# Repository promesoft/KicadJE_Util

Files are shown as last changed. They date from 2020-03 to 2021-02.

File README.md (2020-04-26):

# KicadJE_Util
CV utility module

# Purpose

## CV Util 1
Input +/- 10V DC

Output +/- 10V DC

Adjustment:

Inv/Noninv (input)

Offset

Gain 

## CV Util 2 - Glide
0-10V input

0-10V Output

## Gate Util 1 - Timing
0-10V input

Time shift of the start and end phase

# Status - TimeShift mounted
## Initial 
| Stage  | Detail | Status |
| --- | --- | --- |
| create material  | sch | ok |
| | pcb | ok |
| | gerber | ok |
| production  | | ok |
|  | produced | ok |
|  | delivered | ok |
## Preliminary validation
| Test  | Detail | Status |
| --- | --- | --- |
| Initial Inspection | | ok |
| Initial Technical Test | Util | ok - but offset pots are reversed |
| Initial Technical Test | Glide | notok - CV in potential burn of output by gnd of tip |
| Initial Technical Test | TimeShift | Ok - but problem in pos/neg detection |
| Initial Product Test | Util |  |
| Initial Product Test | Glide |  |
| Initial Product Test | TimeShift |  |

## Secondary validation
| Test  | Detail | Status |
| --- | --- |--- |
| Product Test | Util | |
| Product Test | Glide | |
| Product Test | TimeShift | |
| Quality | Util | |
| Quality | Glide | |
| Quality | TimeShift | |
| Long Term Product Test |  |  |
| Power Draw |  | 

## Errata
### Errata - 

## Issues and Notes
### 

# Pictures
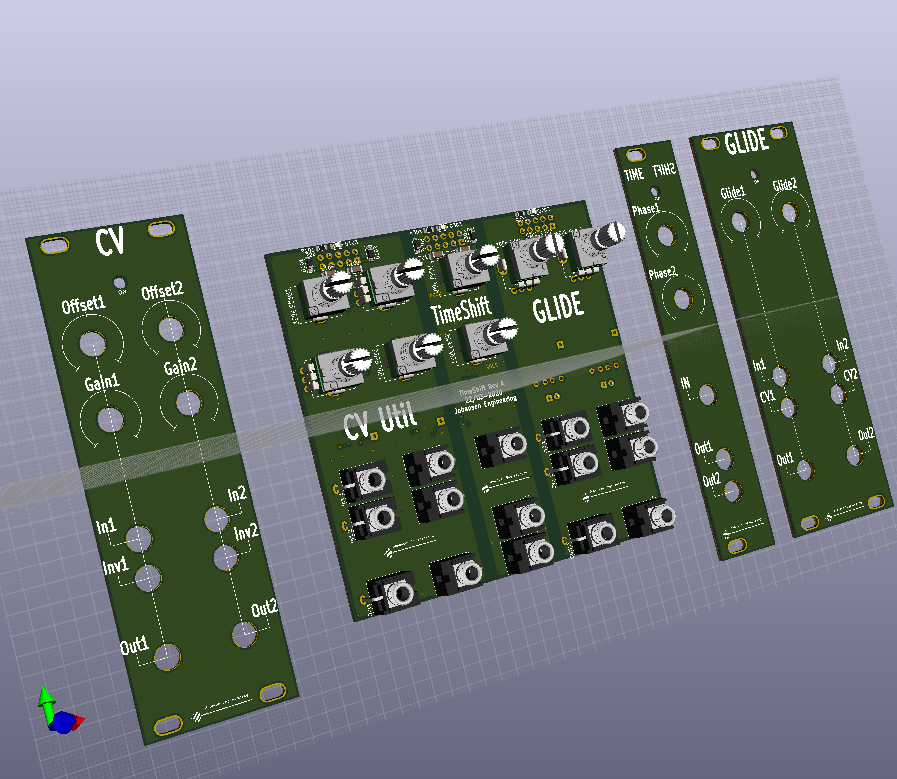
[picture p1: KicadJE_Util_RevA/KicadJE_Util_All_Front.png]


# Schematic
## DC util
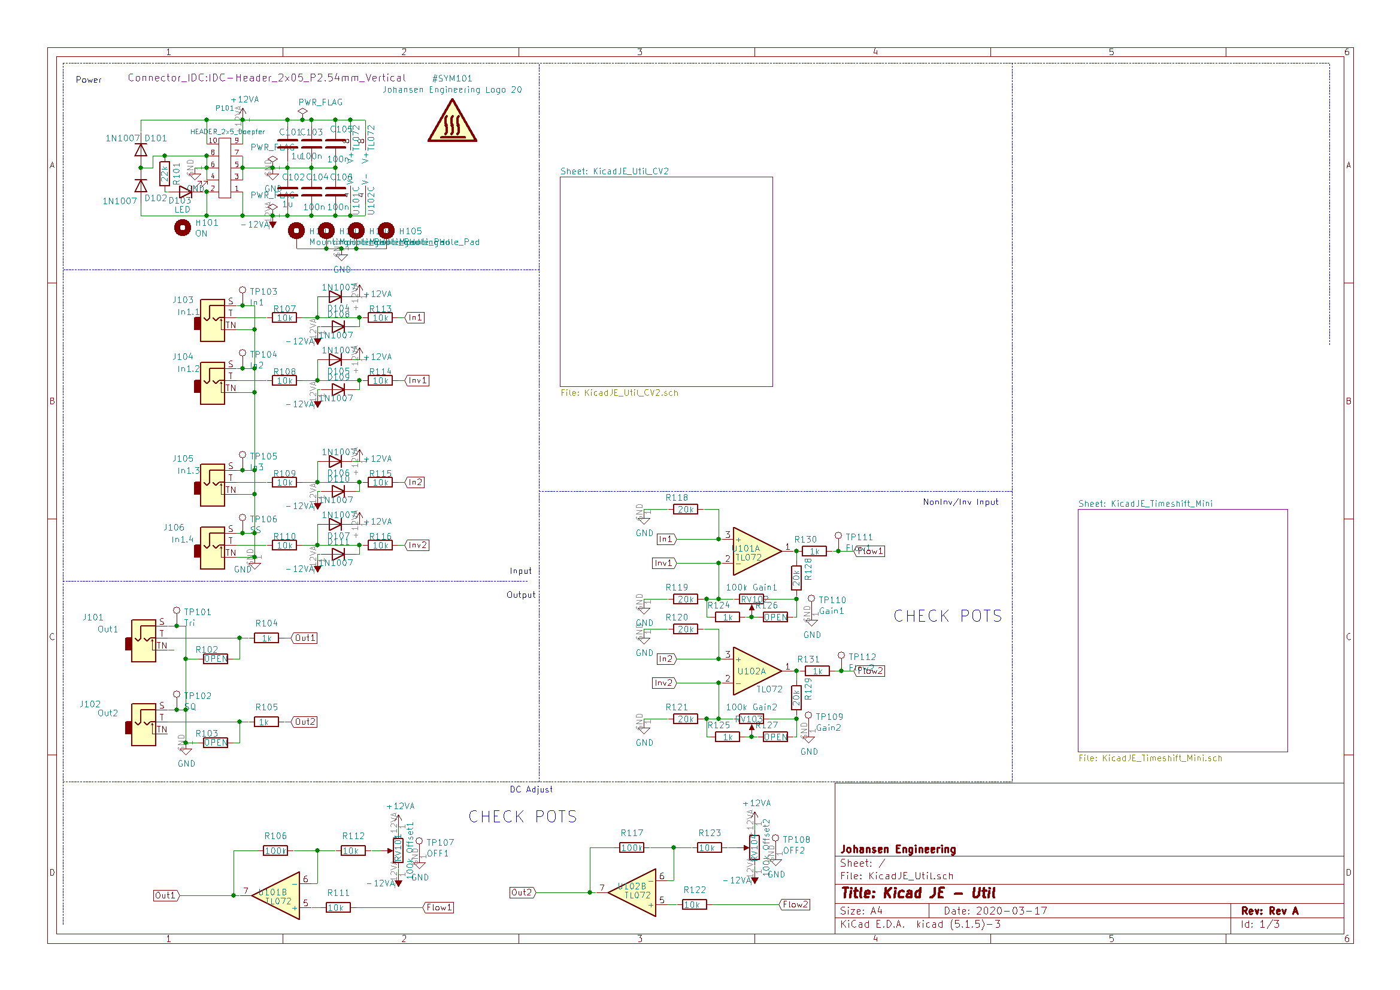
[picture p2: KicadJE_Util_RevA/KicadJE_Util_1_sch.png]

## Glide util
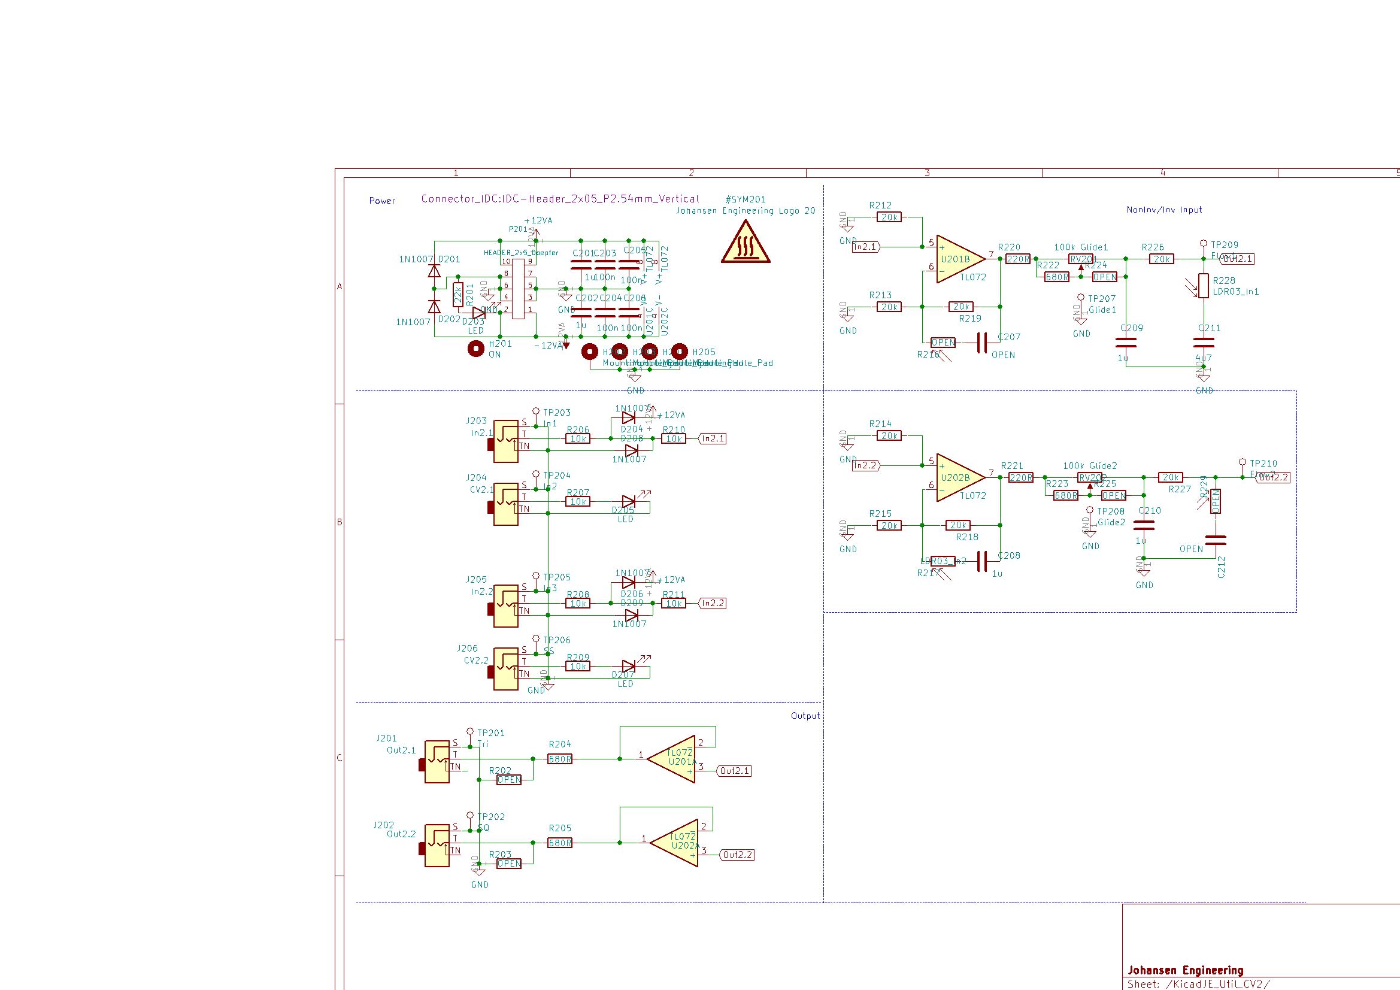
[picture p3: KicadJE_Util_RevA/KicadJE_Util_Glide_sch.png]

## TimeShift util
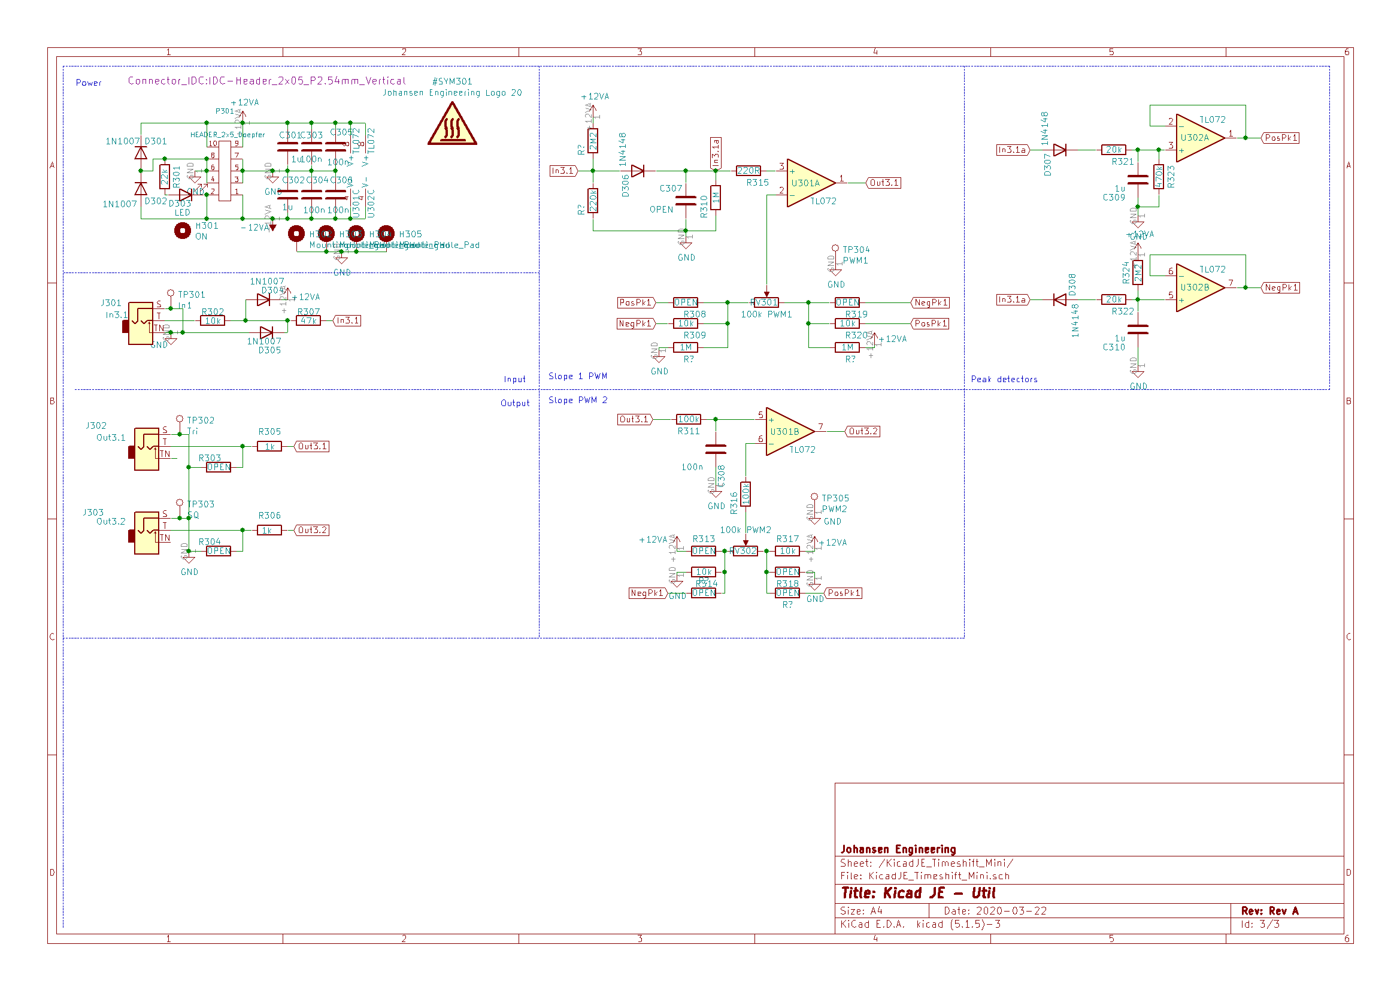
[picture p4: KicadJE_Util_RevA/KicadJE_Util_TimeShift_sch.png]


# Analysis
## Timeshift


## Prototype

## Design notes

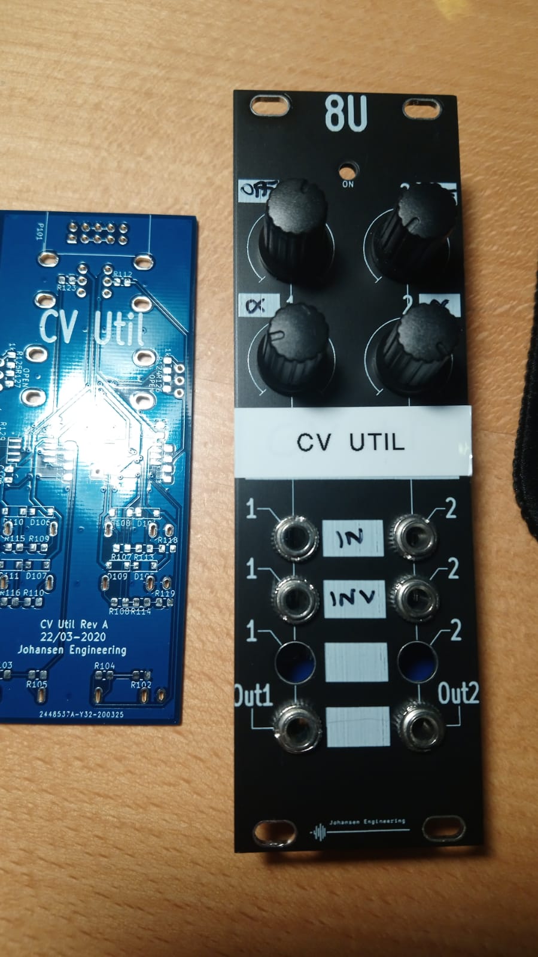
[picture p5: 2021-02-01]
CV-Util.jpeg

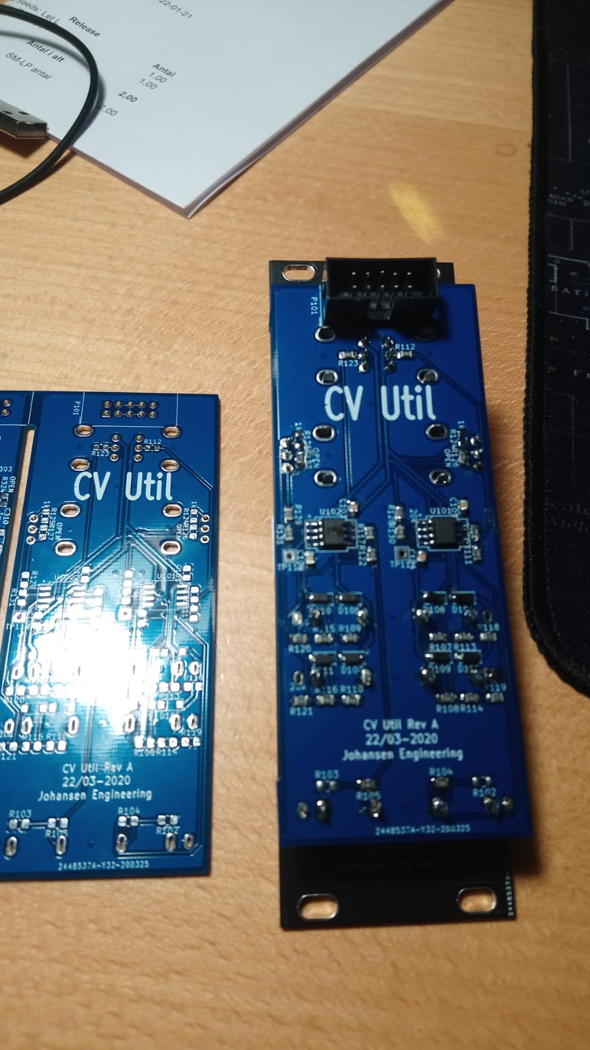
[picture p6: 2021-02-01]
CV-Util-back.jpeg

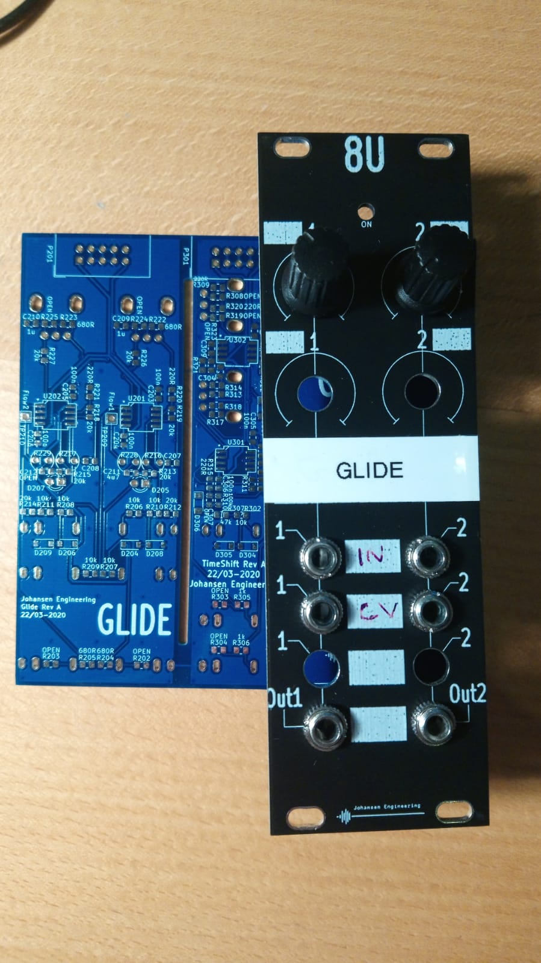
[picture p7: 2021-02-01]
Glide.jpeg

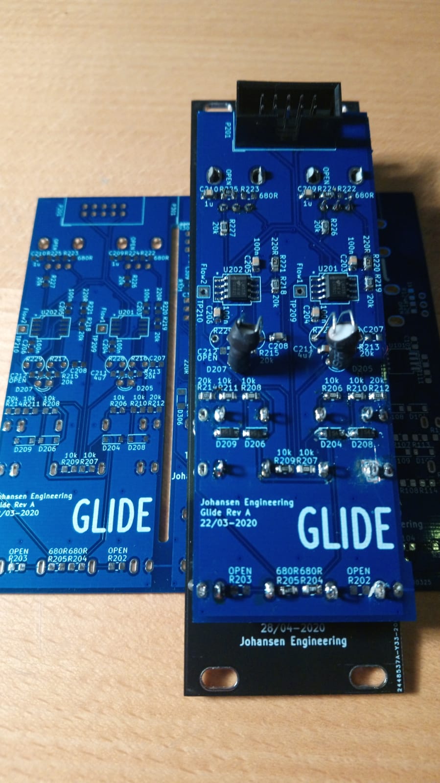
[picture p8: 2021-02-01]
Glide back.jpeg

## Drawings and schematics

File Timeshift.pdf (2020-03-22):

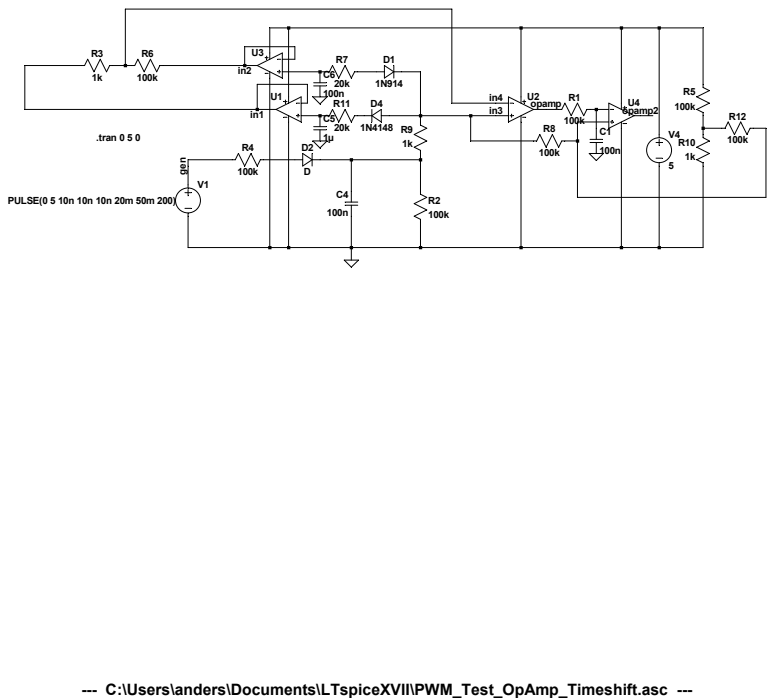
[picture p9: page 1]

--- C:\Users\anders\Documents\LTspiceXVII\PWM_Test_OpAmp_Timeshift.asc ---

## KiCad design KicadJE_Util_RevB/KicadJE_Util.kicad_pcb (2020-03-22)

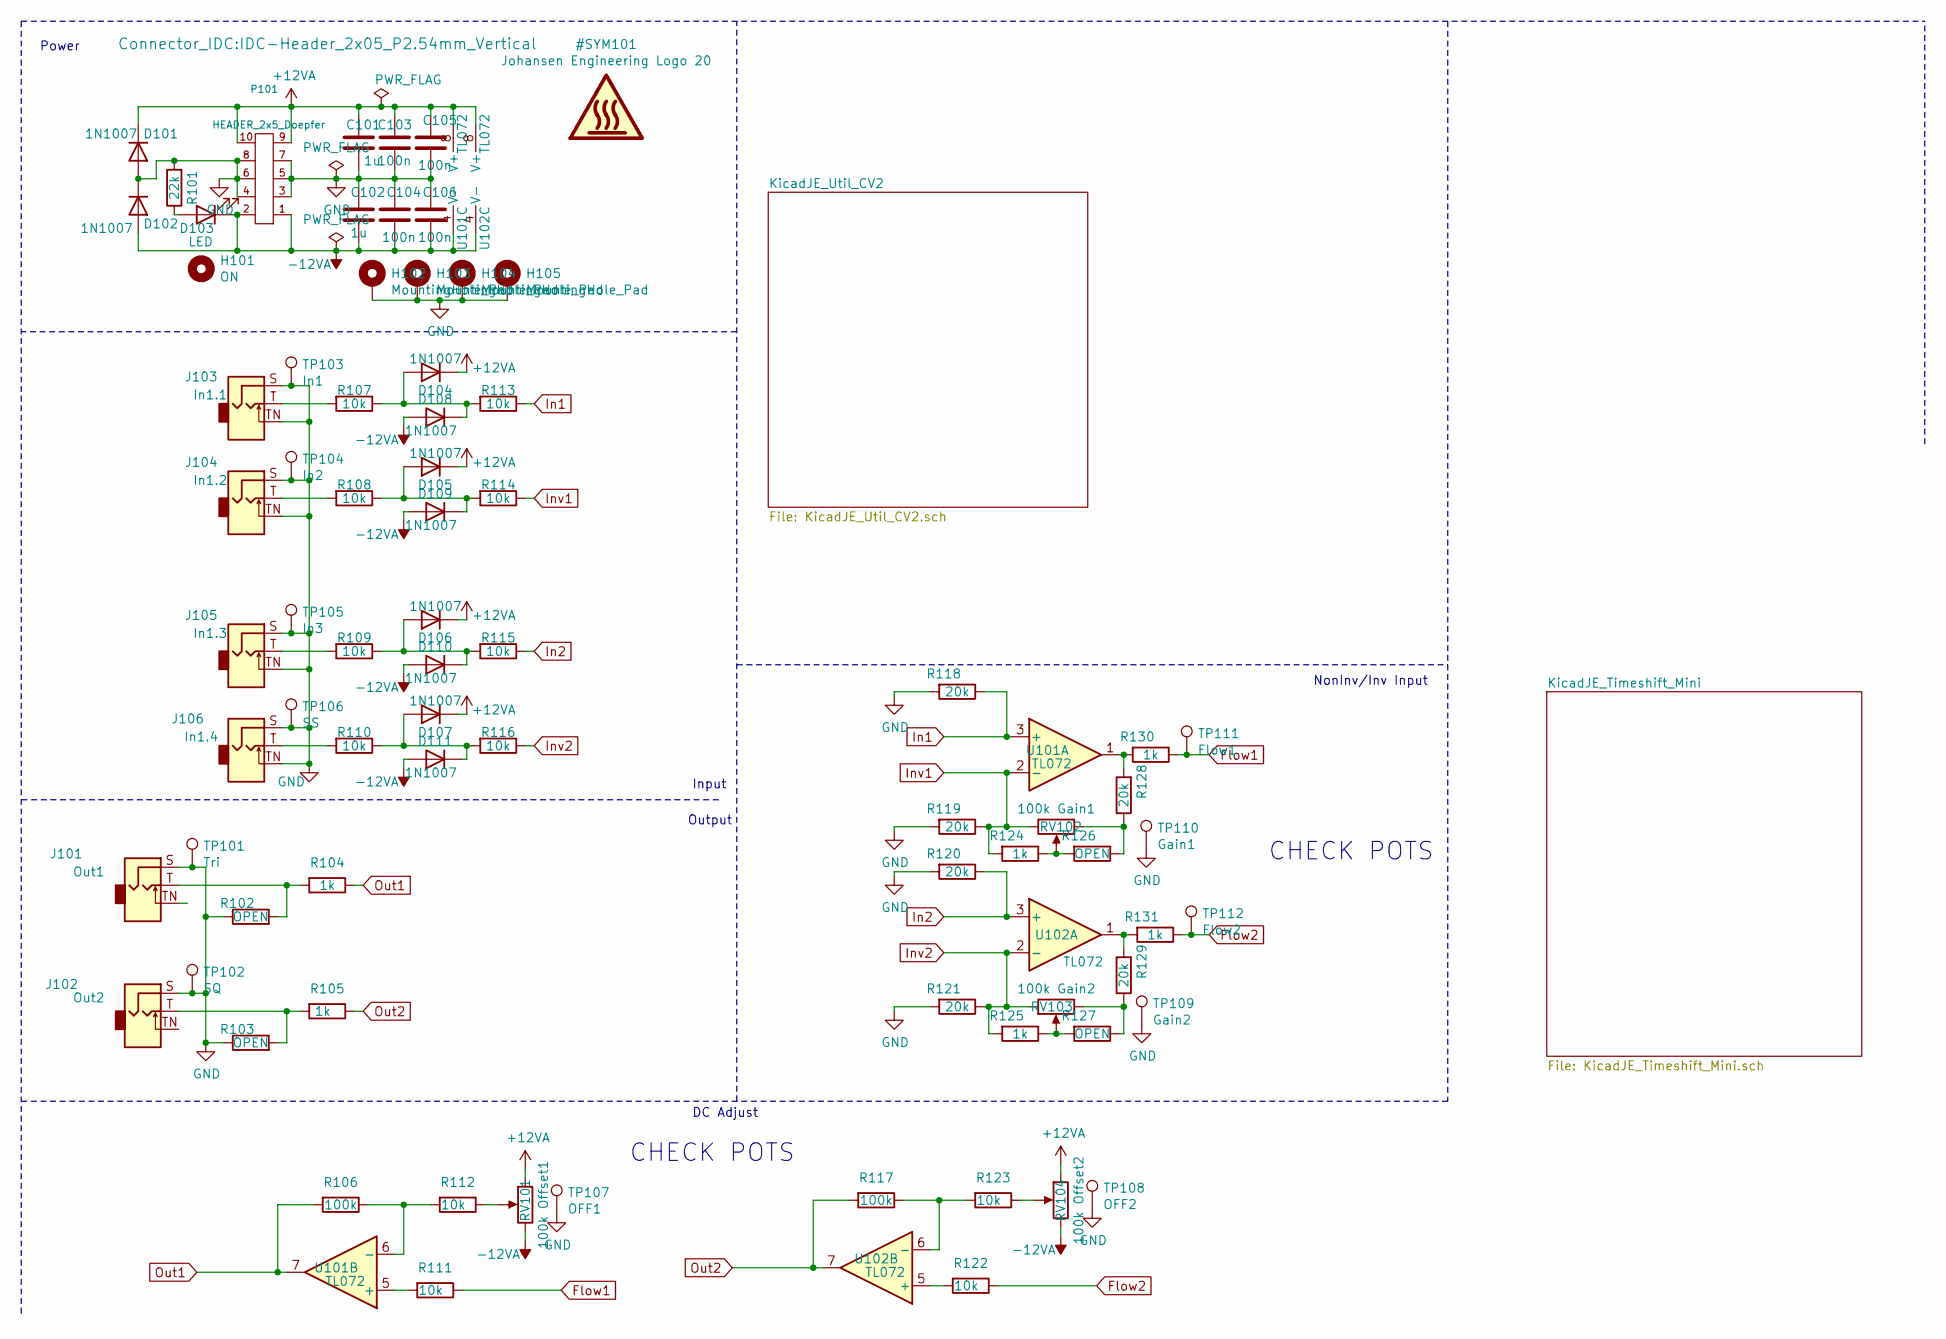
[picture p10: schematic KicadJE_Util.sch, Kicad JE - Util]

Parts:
C101, C102: 1u; C_1206_3216Metric_Pad1.42x1.75mm_HandSolder
C103, C104, C105, C106: 100n; C_0805_2012Metric_Pad1.15x1.40mm_HandSolder
D101, D102, D104, D105, D106, D107, D108, D109, D110, D111: 1N1007; D_SOD-123
D103: LED; LED_0805_2012Metric_Pad1.15x1.40mm_HandSolder
H101: ON; LED_Hole_3mm
H102, H103, H104, H105: MountingHole_Pad; MountingHole_Eurorack3
J101: Out1; PJ301SM
J102: Out2; PJ301SM
J103: In1.1; PJ301SM
J104: In1.2; PJ301SM
J105: In1.3; PJ301SM
J106: In1.4; PJ301SM
P101: HEADER_2x5_Doepfer; IDC-Header_2x05_P2.54mm_Vertical
R101: 22k; R_0805_2012Metric_Pad1.15x1.40mm_HandSolder
R102, R103, R126, R127: OPEN; R_0805_2012Metric_Pad1.15x1.40mm_HandSolder
R104, R105, R124, R125, R130, R131: 1k; R_0805_2012Metric_Pad1.15x1.40mm_HandSolder
R106, R117: 100k; R_0805_2012Metric_Pad1.15x1.40mm_HandSolder
R107, R108, R109, R110, R111, R112, R113, R114, R115, R116, R122, R123: 10k; R_0805_2012Metric_Pad1.15x1.40mm_HandSolder
R118, R119, R120, R121, R128, R129: 20k; R_0805_2012Metric_Pad1.15x1.40mm_HandSolder
RV101: 100k Offset1; Potentiometer_China_RK09_Single_Vertical_AJ
RV102: 100k Gain1; Potentiometer_China_RK09_Single_Vertical_AJ
RV103: 100k Gain2; Potentiometer_China_RK09_Single_Vertical_AJ
RV104: 100k Offset2; Potentiometer_China_RK09_Single_Vertical_AJ
TP101: Tri; Jack_6m3
TP102: SQ; Jack_6m3
TP103: In1; Jack_6m3
TP104: In2; Jack_6m3
TP105: In3; Jack_6m3
TP106: SS; Jack_6m3
TP107: OFF1; Pot_6m3_scale1
TP108: OFF2; Pot_6m3_scale1
TP109: Gain2; Pot_6m3_scale1
TP110: Gain1; Pot_6m3_scale1
TP111: Flow1; TestPoint_THTPad_2.0x2.0mm_Drill1.0mm
TP112: Flow2; TestPoint_THTPad_2.0x2.0mm_Drill1.0mm
U101, U102: TL072; AJ_SO-8_5.3x6.2mm_P1.27mm

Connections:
+12VA: C101.1, C103.1, C105.1, D101.1 (K), D104.1 (K), D105.1 (K), D106.1 (K), D107.1 (K), P101.9 (+12), P101.10 (+12), RV101.1, RV104.1, U101.8 (V+), U102.8 (V+); also elsewhere on the board
-12VA: C102.2, C104.2, C106.2, D102.2 (A), D103.1 (K), D108.2 (A), D109.2 (A), D110.2 (A), D111.2 (A), P101.1 (-12), P101.2 (-12), RV101.3, RV104.3, U101.4 (V-), U102.4 (V-); also elsewhere on the board
Flow1: R111.1, R130.1, TP111.1
In1: R113.1, R118.1, U101.3 (+)
In2: R115.1, R120.1, U102.3 (+)
Inv1: R114.1, R119.1, R124.2, RV102.3, U101.2 (-)
Inv2: R116.1, R121.1, R125.2, RV103.1, U102.2 (-)
unnamed: D103.2 (A), R101.1
unnamed: D104.2 (A), D108.1 (K), R107.1, R113.2
unnamed: D105.2 (A), D109.1 (K), R108.1, R114.2
unnamed: D106.2 (A), D110.1 (K), R109.1, R115.2
unnamed: D107.2 (A), D111.1 (K), R110.1, R116.2
unnamed: J101.T, R102.2, R104.2
unnamed: J102.T, R103.2, R105.2
unnamed: J103.T, R107.2
unnamed: J104.T, R108.2
unnamed: J105.T, R109.2
unnamed: J106.T, R110.2
unnamed: R106.1, R112.2, U101.6 (-)
unnamed: R111.2, U101.5 (+)
unnamed: R112.1, RV101.2
unnamed: R117.1, R123.2, U102.6 (-)
unnamed: R122.2, U102.5 (+)
unnamed: R123.1, RV104.2
unnamed: R124.1, R126.2, RV102.2
unnamed: R125.1, R127.2, RV103.2
unnamed: R126.1, R128.1, RV102.1
unnamed: R127.1, R129.1, RV103.3
unnamed: R128.2, R130.2, U101.1
unnamed: R129.2, R131.2, U102.1
Out1: R104.1, R106.2, U101.7
Out2: R105.1, R117.2, U102.7

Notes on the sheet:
DC Adjust
Power
NonInv/Inv Input
Input
Output
CHECK POTS

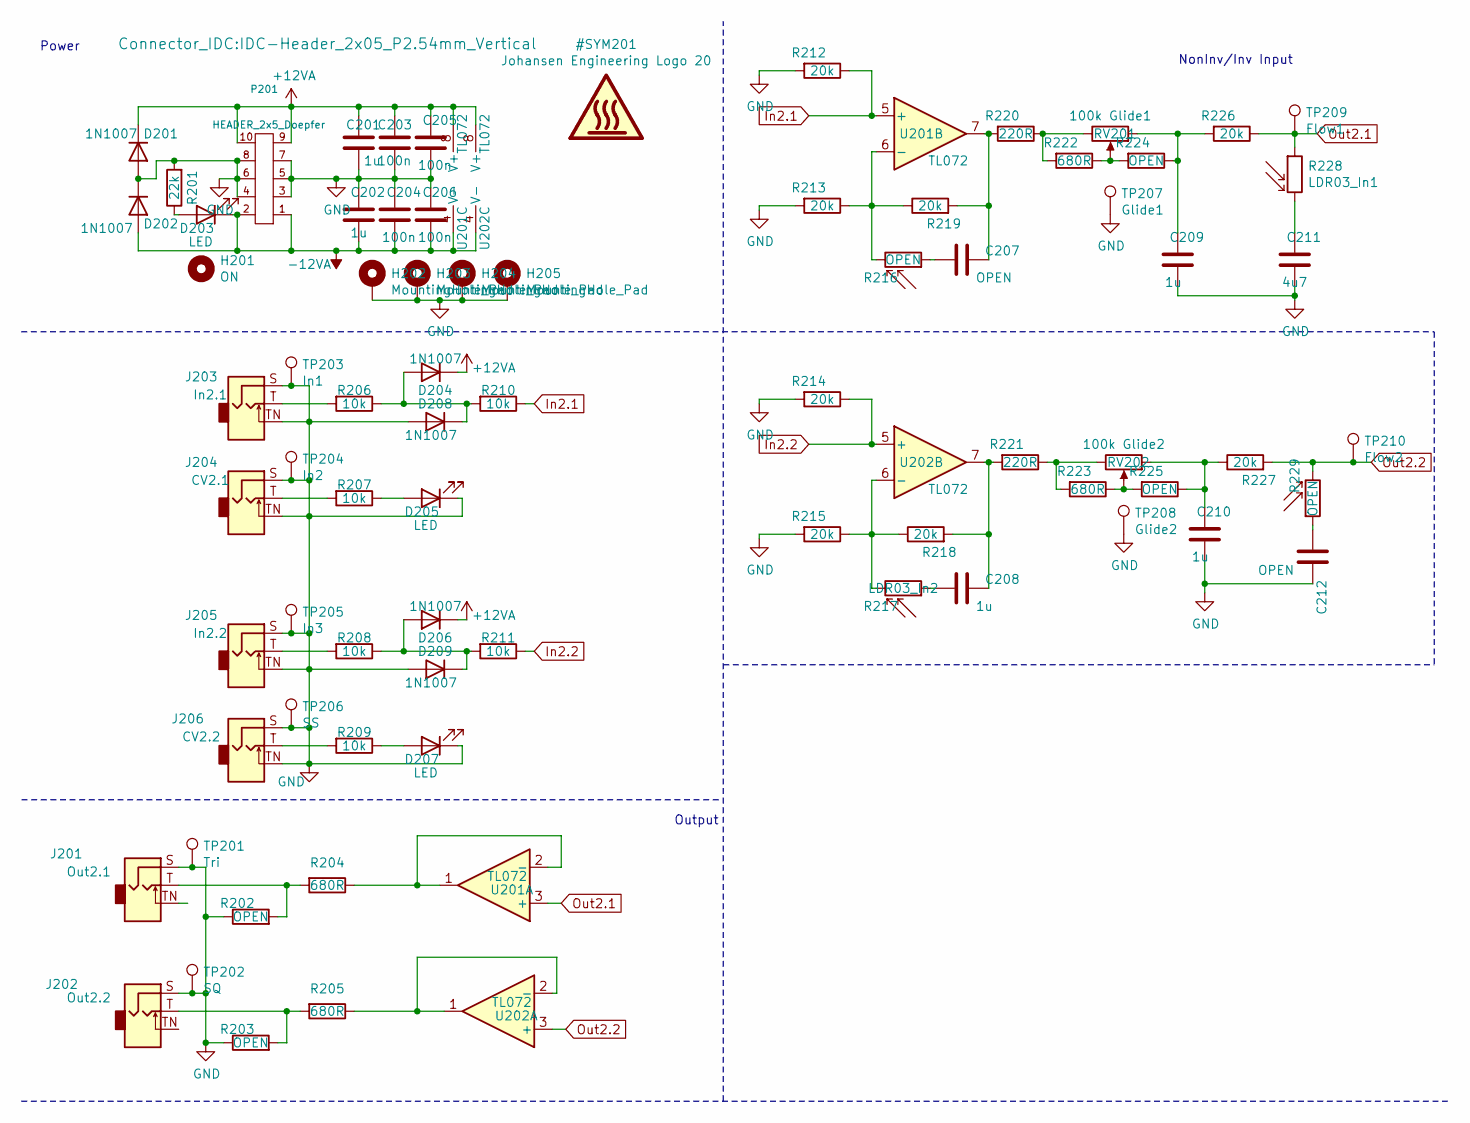
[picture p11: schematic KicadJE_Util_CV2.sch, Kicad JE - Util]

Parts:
C201, C202: 1u; C_1206_3216Metric_Pad1.42x1.75mm_HandSolder
C203, C204, C205, C206: 100n; C_0805_2012Metric_Pad1.15x1.40mm_HandSolder
C207, C212: OPEN; C_0805_2012Metric_Pad1.15x1.40mm_HandSolder
C208, C209, C210: 1u; C_0805_2012Metric_Pad1.15x1.40mm_HandSolder
C211: 4u7; C_0805_2012Metric_Pad1.15x1.40mm_HandSolder
D201, D202, D204, D206, D208, D209: 1N1007; D_SOD-123
D203: LED; LED_0805_2012Metric_Pad1.15x1.40mm_HandSolder
D205, D207: LED; LED_D3.0mm
H201: ON; LED_Hole_3mm
H202, H203, H204, H205: MountingHole_Pad; MountingHole_Eurorack3
J201: Out2.1; PJ301SM
J202: Out2.2; PJ301SM
J203: In2.1; PJ301SM
J204: CV2.1; PJ301SM
J205: In2.2; PJ301SM
J206: CV2.2; PJ301SM
P201: HEADER_2x5_Doepfer; IDC-Header_2x05_P2.54mm_Vertical
R201: 22k; R_0805_2012Metric_Pad1.15x1.40mm_HandSolder
R202, R203, R224, R225: OPEN; R_0805_2012Metric_Pad1.15x1.40mm_HandSolder
R204, R205, R222, R223: 680R; R_0805_2012Metric_Pad1.15x1.40mm_HandSolder
R206, R207, R208, R209, R210, R211: 10k; R_0805_2012Metric_Pad1.15x1.40mm_HandSolder
R212, R213, R214, R215, R218, R219, R226, R227: 20k; R_0805_2012Metric_Pad1.15x1.40mm_HandSolder
R216, R229: OPEN; R_LDR_5.0x4.1mm_P3mm_Vertical
R217: LDR03_In2; R_LDR_5.0x4.1mm_P3mm_Vertical
R220, R221: 220R; R_0805_2012Metric_Pad1.15x1.40mm_HandSolder
R228: LDR03_In1; R_LDR_5.0x4.1mm_P3mm_Vertical
RV201: 100k Glide1; Potentiometer_China_RK09_Single_Vertical_AJ
RV202: 100k Glide2; Potentiometer_China_RK09_Single_Vertical_AJ
TP201: Tri; Jack_6m3
TP202: SQ; Jack_6m3
TP203: In1; Jack_6m3
TP204: In2; Jack_6m3
TP205: In3; Jack_6m3
TP206: SS; Jack_6m3
TP207: Glide1; Pot_6m3_scale1
TP208: Glide2; Pot_6m3_scale1
TP209: Flow1; TestPoint_THTPad_2.0x2.0mm_Drill1.0mm
TP210: Flow2; TestPoint_THTPad_2.0x2.0mm_Drill1.0mm
U201, U202: TL072; AJ_SO-8_5.3x6.2mm_P1.27mm

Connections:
+12VA: C201.1, C203.1, C205.1, D201.1 (K), D204.1 (K), D206.1 (K), P201.9 (+12), P201.10 (+12), U201.8 (V+), U202.8 (V+); also elsewhere on the board
-12VA: C202.2, C204.2, C206.2, D202.2 (A), D203.1 (K), P201.1 (-12), P201.2 (-12), U201.4 (V-), U202.4 (V-); also elsewhere on the board
In2.1: R210.1, R212.1, U201.5 (+)
In2.2: R211.1, R214.1, U202.5 (+)
unnamed: C207.1, R219.2, R220.2, U201.7
unnamed: C207.2, R216.1
unnamed: C208.1, R218.2, R221.2, U202.7
unnamed: C208.2, R217.1
unnamed: C209.1, R224.1, R226.2, RV201.1
unnamed: C210.1, R225.1, R227.1, RV202.1
unnamed: C211.1, R228.2
unnamed: C212.2, R229.1
unnamed: D203.2 (A), R201.1
unnamed: D204.2 (A), D208.1 (K), R206.1, R210.2
unnamed: D205.2 (A), R207.1
unnamed: D206.2 (A), D209.1 (K), R208.1, R211.2
unnamed: D207.2 (A), R209.1
unnamed: J201.T, R202.2, R204.2
unnamed: J202.T, R203.2, R205.2
unnamed: J203.T, R206.2
unnamed: J204.T, R207.2
unnamed: J205.T, R208.2
unnamed: J206.T, R209.2
unnamed: R204.1, U201.1, U201.2 (-)
unnamed: R205.1, U202.1, U202.2 (-)
unnamed: R213.1, R216.2, R219.1, U201.6 (-)
unnamed: R215.1, R217.2, R218.1, U202.6 (-)
unnamed: R220.1, R222.2, RV201.3
unnamed: R221.1, R223.2, RV202.3
unnamed: R222.1, R224.2, RV201.2
unnamed: R223.1, R225.2, RV202.2
Out2.1: R226.1, R228.1, TP209.1, U201.3 (+)
Out2.2: R227.2, R229.2, TP210.1, U202.3 (+)

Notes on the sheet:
Power
NonInv/Inv Input
Output

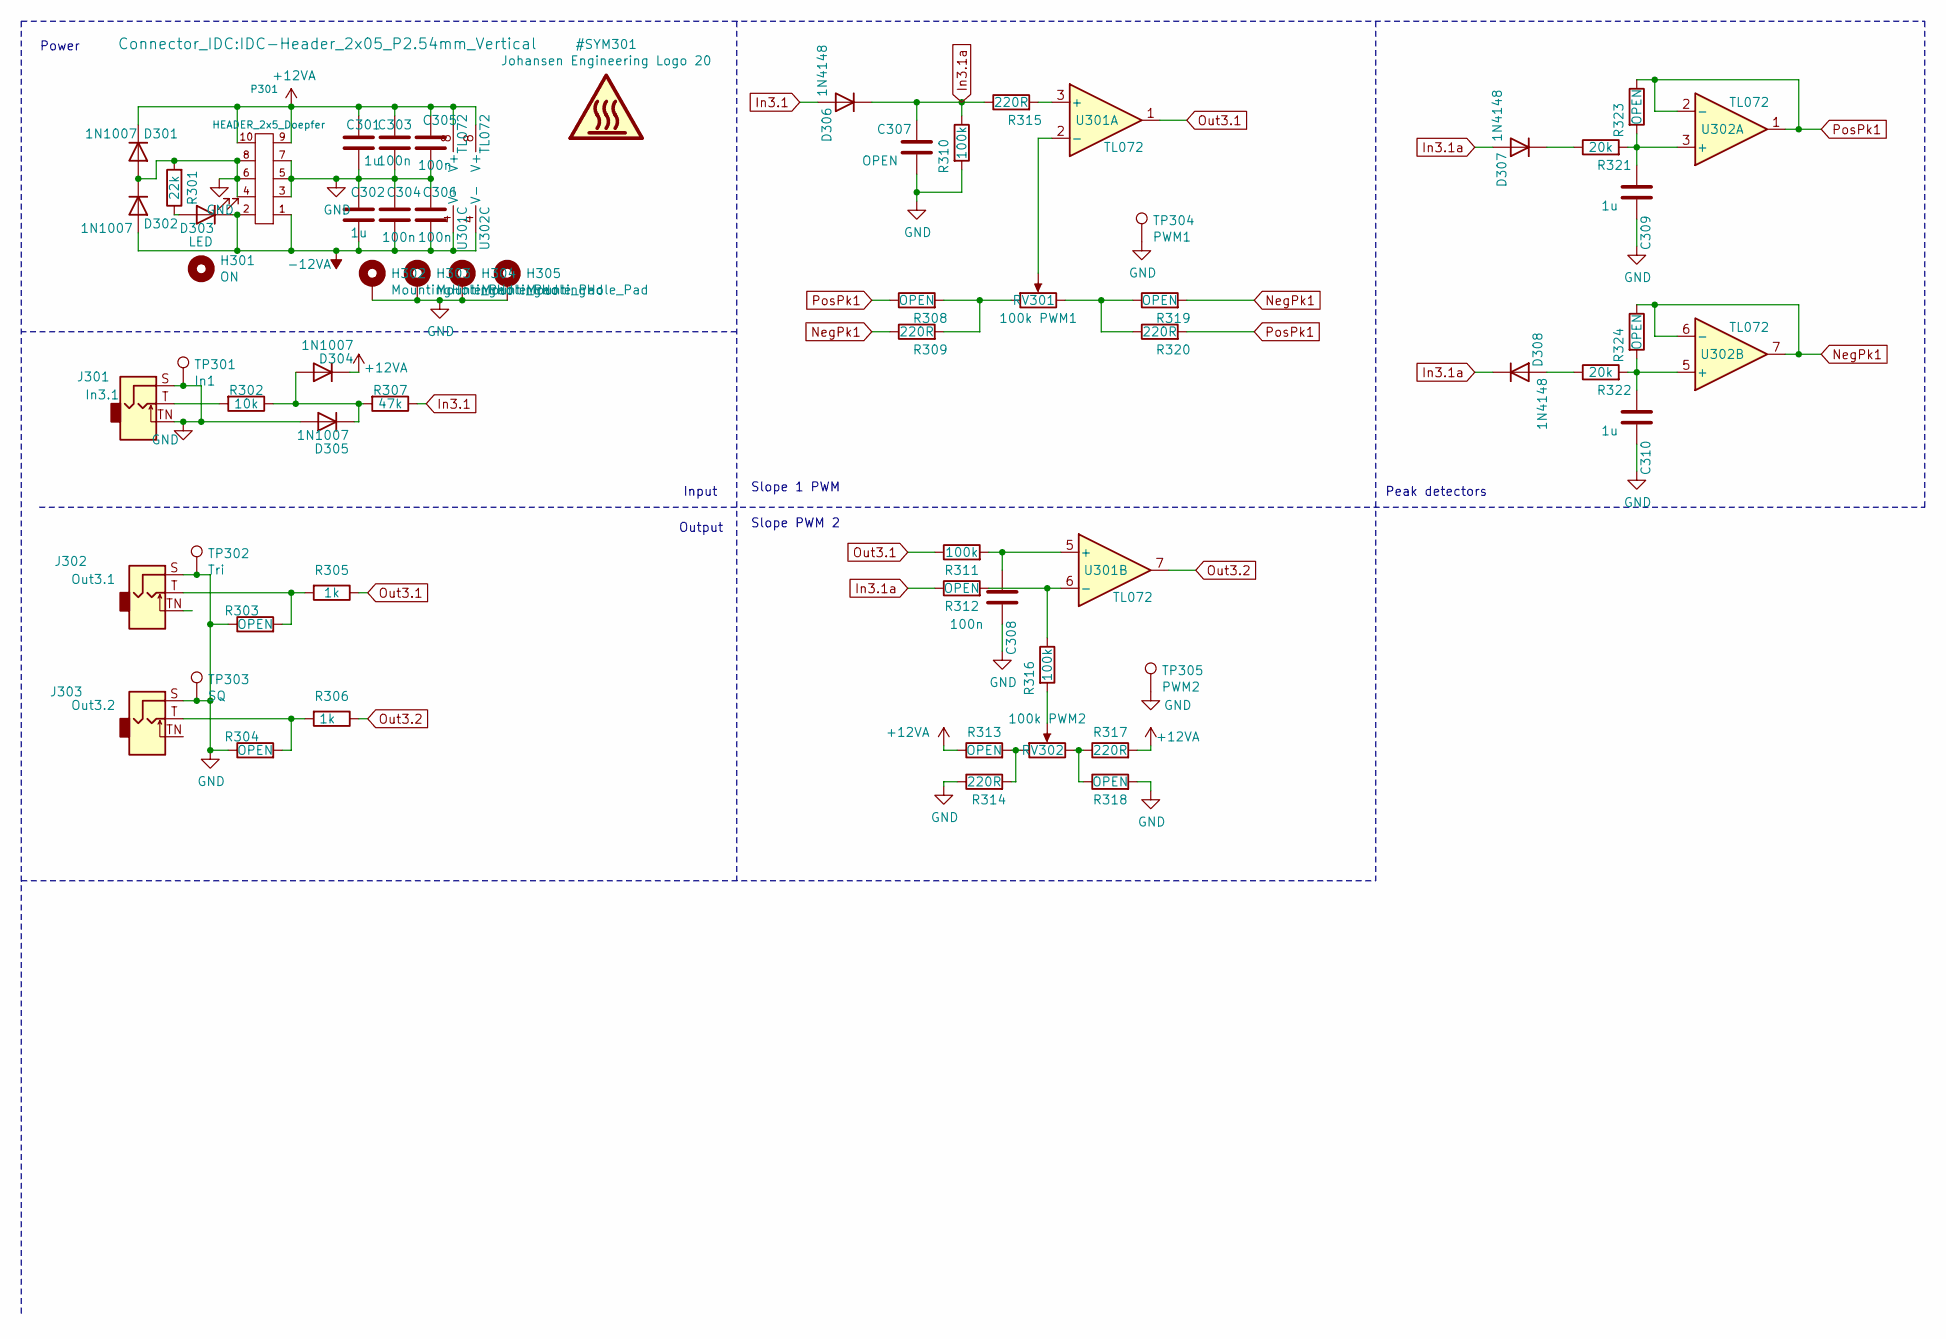
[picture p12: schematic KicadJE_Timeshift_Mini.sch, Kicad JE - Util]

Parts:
C301, C302: 1u; C_1206_3216Metric_Pad1.42x1.75mm_HandSolder
C303, C304, C305, C306, C308: 100n; C_0805_2012Metric_Pad1.15x1.40mm_HandSolder
C307: OPEN; C_0805_2012Metric_Pad1.15x1.40mm_HandSolder
C309, C310: 1u; C_0805_2012Metric_Pad1.15x1.40mm_HandSolder
D301, D302, D304, D305: 1N1007; D_SOD-123
D303: LED; LED_0805_2012Metric_Pad1.15x1.40mm_HandSolder
D306, D307, D308: 1N4148; D_MiniMELF
H301: ON; LED_Hole_3mm
H302, H303, H304, H305: MountingHole_Pad; MountingHole_Eurorack3
J301: In3.1; PJ301SM
J302: Out3.1; PJ301SM
J303: Out3.2; PJ301SM
P301: HEADER_2x5_Doepfer; IDC-Header_2x05_P2.54mm_Vertical
R301: 22k; R_0805_2012Metric_Pad1.15x1.40mm_HandSolder
R302: 10k; R_0805_2012Metric_Pad1.15x1.40mm_HandSolder
R303, R304, R308, R312, R313, R318, R319, R323, R324: OPEN; R_0805_2012Metric_Pad1.15x1.40mm_HandSolder
R305, R306: 1k; R_0805_2012Metric_Pad1.15x1.40mm_HandSolder
R307: 47k; R_0805_2012Metric_Pad1.15x1.40mm_HandSolder
R309, R314, R315, R317, R320: 220R; R_0805_2012Metric_Pad1.15x1.40mm_HandSolder
R310, R311, R316: 100k; R_0805_2012Metric_Pad1.15x1.40mm_HandSolder
R321, R322: 20k; R_0805_2012Metric_Pad1.15x1.40mm_HandSolder
RV301: 100k PWM1; Potentiometer_China_RK09_Single_Vertical_AJ
RV302: 100k PWM2; Potentiometer_China_RK09_Single_Vertical_AJ
TP301: In1; Jack_6m3
TP302: Tri; Jack_6m3
TP303: SQ; Jack_6m3
TP304: PWM1; Pot_6m3_scale1
TP305: PWM2; Pot_6m3_scale1
U301, U302: TL072; AJ_SO-8_5.3x6.2mm_P1.27mm

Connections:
+12VA: C301.1, C303.1, C305.1, D301.1 (K), D304.1 (K), P301.9 (+12), P301.10 (+12), R313.1, R317.2, U301.8 (V+), U302.8 (V+); also elsewhere on the board
-12VA: C302.2, C304.2, C306.2, D302.2 (A), D303.1 (K), P301.1 (-12), P301.2 (-12), U301.4 (V-), U302.4 (V-); also elsewhere on the board
In3.1: D306.2 (A), R307.1
In3.1a: C307.2, D306.1 (K), D307.2 (A), D308.1 (K), R310.1, R312.1, R315.1
NegPk1: R309.1, R319.2, R324.1, U302.6 (-), U302.7
unnamed: C308.2, R311.2, U301.5 (+)
unnamed: C309.2, R321.2, R323.2, U302.3 (+)
unnamed: C310.2, R322.2, R324.2, U302.5 (+)
unnamed: D303.2 (A), R301.1
unnamed: D304.2 (A), D305.1 (K), R302.1, R307.2
unnamed: D307.1 (K), R321.1
unnamed: D308.2 (A), R322.1
unnamed: J301.T, R302.2
unnamed: J302.T, R303.2, R305.2
unnamed: J303.T, R304.2, R306.2
unnamed: R308.2, R309.2, RV301.1
unnamed: R312.2, R316.1, U301.6 (-)
unnamed: R313.2, R314.2, RV302.1
unnamed: R315.2, U301.3 (+)
unnamed: R316.2, RV302.2
unnamed: R317.1, R318.1, RV302.3
unnamed: R319.1, R320.1, RV301.3
unnamed: RV301.2, U301.2 (-)
Out3.1: R305.1, R311.1, U301.1
Out3.2: R306.1, U301.7
PosPk1: R308.1, R320.2, R323.1, U302.1, U302.2 (-)

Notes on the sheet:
Power
Input
Output
Slope 1 PWM
Peak detectors
Slope PWM 2

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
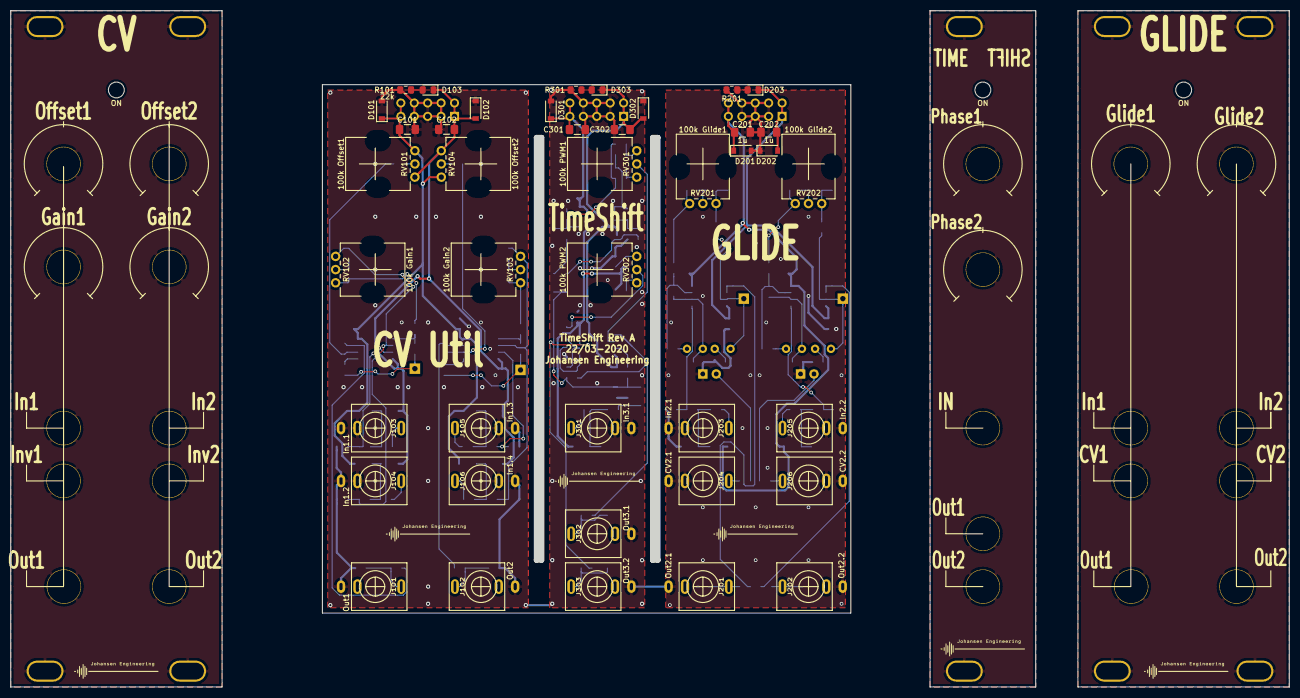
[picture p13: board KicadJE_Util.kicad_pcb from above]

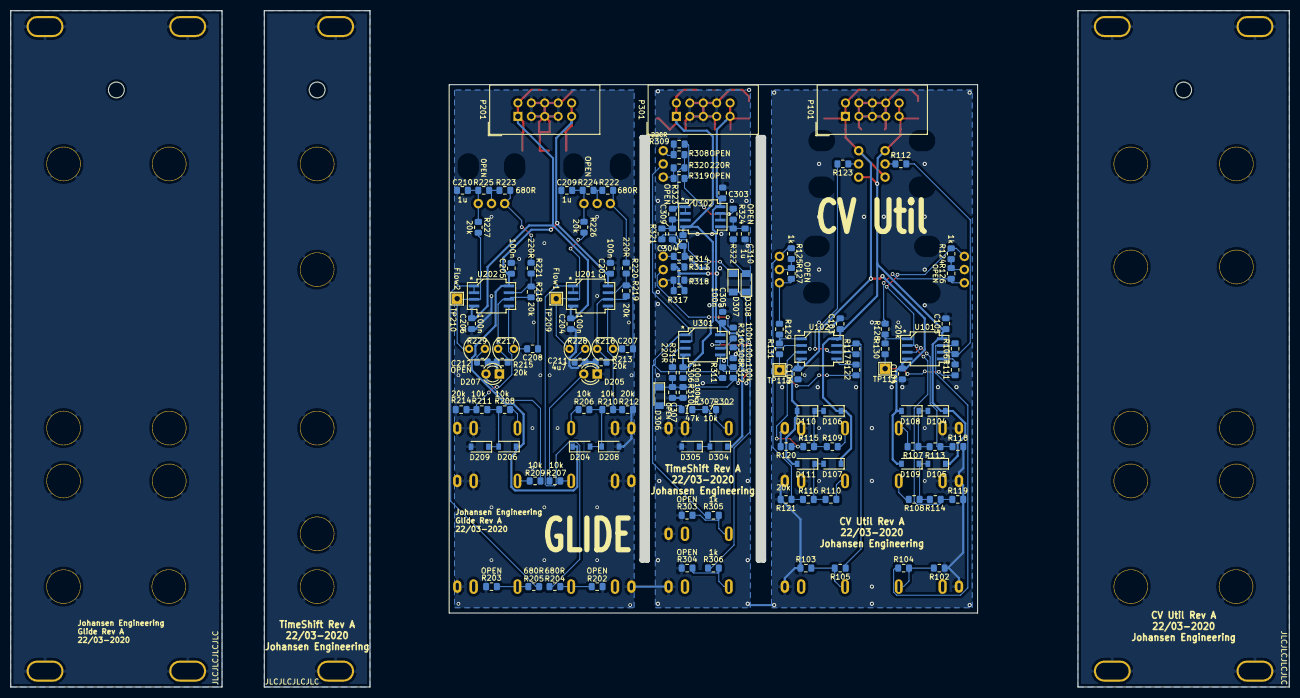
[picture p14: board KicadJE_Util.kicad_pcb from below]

Board: 2 copper layers, 100.0 x 100.0 mm, 212 parts (140 on the bottom side), 89 nets.

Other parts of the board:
H101#2: ON; LED_Hole_3mm
H102#2, H102#3, H103#2, H103#3, H104#2, H105#2: MountingHole_Pad; MountingHole_Eurorack3
TP102#2: SQ; Jack_6m3
TP103#2: In1; Jack_6m3
TP105#2: In3; Jack_6m3
TP106#2: HS; Jack_6m3
TP107#2, TP107#5: OFF1; Pot_6m3_scale1
TP107#3, TP107#4: FM; Jack_6m3
TP108#2: PWM; Jack_6m3
TP112#2, TP112#3: Fine; Pot_6m3_scale1
TP112#4: Flow2; TestPoint_THTPad_2.0x2.0mm_Drill1.0mm

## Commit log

2020-03-17 Initial documents
    [KicadJE_Util.kicad_pcb, KicadJE_Util.sch]
2020-03-17 Base sch done
    [KicadJE_Util.sch, KicadJE_Util_CV2.sch]
2020-03-19 fix flow
    [KicadJE_Util.sch, KicadJE_Util_CV2.sch]
2020-03-19 Glide initiated
    [KicadJE_Util_CV2.sch]
2020-03-21 Update KicadJE_Util_CV2.sch
    Glide
    [KicadJE_Util_CV2.sch]
2020-03-22 Timeshift Added
    [KicadJE_Timeshift_Mini.sch, KicadJE_Util.sch, KicadJE_Util_CV2.sch]
2020-03-22 Timeshift stage 1
    [KicadJE_Timeshift_Mini.sch]
2020-03-22 PCB Cleanup and new netlist
    [KicadJE_Util.kicad_pcb]
2020-03-22 Placing IO components
    [KicadJE_Util.kicad_pcb]
2020-03-22 Update KicadJE_Timeshift_Mini.sch
    Fixing packaging of OpAmp
    [KicadJE_Timeshift_Mini.sch]
2020-03-22 Faceplace komp placed
    [KicadJE_Util.kicad_pcb, KicadJE_Util.sch]
2020-03-22 Update KicadJE_Util.kicad_pcb
    Time shift placed
    [KicadJE_Util.kicad_pcb]
2020-03-22 Timeshift routed
    [KicadJE_Util.kicad_pcb]
2020-03-22 CV Module placed
    [KicadJE_Util.kicad_pcb, KicadJE_Util.sch]
2020-03-22 CV Util routed - and Timeshift fixed?
    [KicadJE_Util.kicad_pcb]
2020-03-22 Labels and DRC
    [KicadJE_Util.kicad_pcb, KicadJE_Util_CV2.sch]
2020-03-22 PCB only
    [KicadJE_Util_PCB.kicad_pcb]
2020-03-22 JLC Zip
    [KicadJE_Util_PCB.kicad_pcb]
2020-04-22 RevB Initiated
    [KicadJE_Timeshift_Mini.sch, KicadJE_Util.kicad_pcb, KicadJE_Util.sch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]
2020-04-26 input changed
    [KicadJE_Util.sch, KicadJE_Util_CV2.sch]
2020-04-29 Generic Face Gerber
    [KicadJE_Util_Faceplate_Generic-B_Cu.gbr, KicadJE_Util_Faceplate_Generic-B_Mask.gbr, KicadJE_Util_Faceplate_Generic-B_Paste.gbr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]
2024-12-30 attempt to go to Kicad 7
    [KicadJE_Timeshift_Mini.sch, KicadJE_Util.sch, KicadJE_Util_CV2.sch]
